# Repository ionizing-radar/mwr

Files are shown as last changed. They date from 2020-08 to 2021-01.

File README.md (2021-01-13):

# mwr
## Mobile Wheeled Robot library

I'm making a robot, and I want the code to be in more than one place.

## Joystick Controls for Two Wheels

Motor control takes the vector (r, θ) as an input from the joystick, where r spans (0,1) and θ spans (-π, π).

These polar coordinates are translated from (x,y) coordinates of the joystick control, where θ = arctan(Y-offset/X-offset).
###### Note: thats written in Java, so it's Math.arctan**2**(y,x) and not straight up arctan because of course it isn't. X and Y offset have also been translated -π/2, aka 90 degrees counter-clockwise by (x,y) -> (-y,x) so it's actually arctan(x,-y). Confusing at first, but since arctan takes a fraction it saves having to translate the polar coordinate by giving arctan translated cartesian coordinates.

R, or radius, is the strength of the joystick direction. So 1 is full power and 0 is of course full stop, with any value in between.

These polar coordinates assume UP on the joystick is 0 degrees for forwards, and DOWN is π and -π degrees for backwards. (Negative and postive π are equal in terms of the direction of the joystick, since in radians 0 is congruent to 2π). LEFT and RIGHT are hard turns to the LEFT and RIGHT, while 45 degrees LEFT and RIGTH are slow turns. The difference between hard and slow turn is that the motor on the side to turn towards is either reversing or stopped. So for a hard turn LEFT the left motor is full reverse and the right motor is full forwards, and the opposite for a hard turn RIGHT.

For any left turn between 45 degrees and directly forwards, the left motor will slowly increase to full from stop, and between 45 and 90 degrees left the motor will slowly increase reverse speed to full reverse. For forwards movement on the joystick this can be modeled as cos(2θ) and for backwards on the joystick it is sin(2θ-π/2).

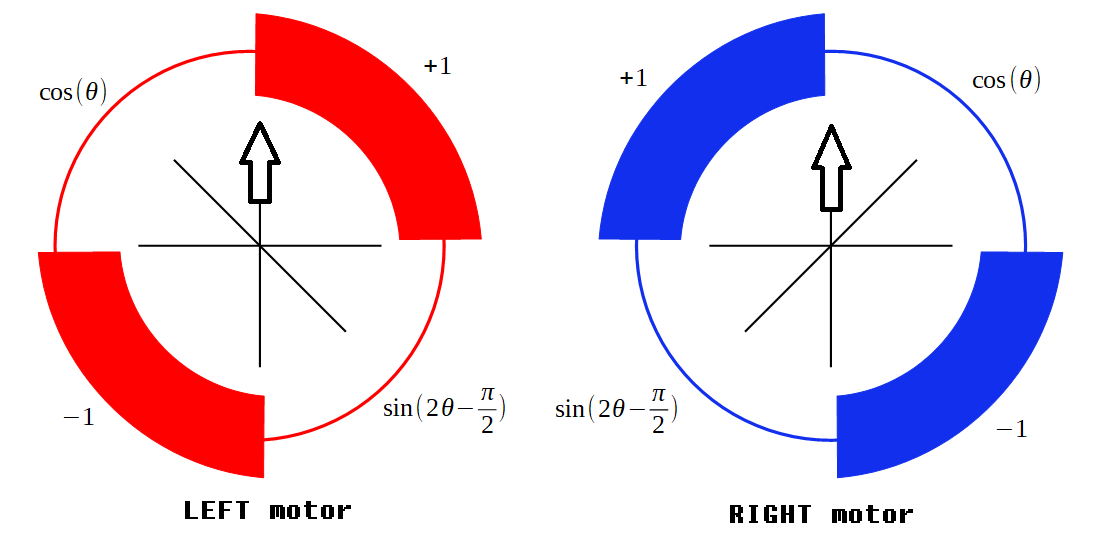
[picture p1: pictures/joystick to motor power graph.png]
Joystick-Motor power graph


###### For more reading on polar coordinates check out https://www.mathsisfun.com/polar-cartesian-coordinates.html and https://mathworld.wolfram.com/PolarCoordinates.html

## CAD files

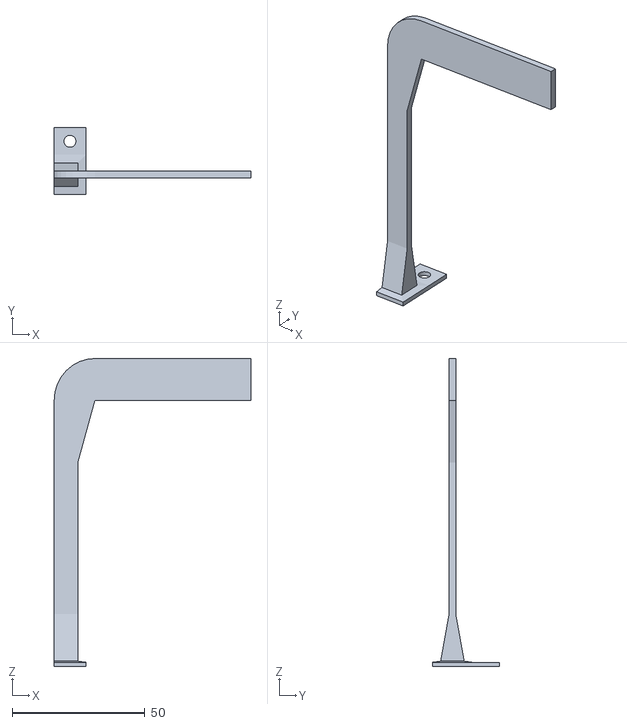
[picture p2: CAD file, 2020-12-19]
shapes/camera_gimbal/camera mount.stl
74.1 x 25.2 x 115.9

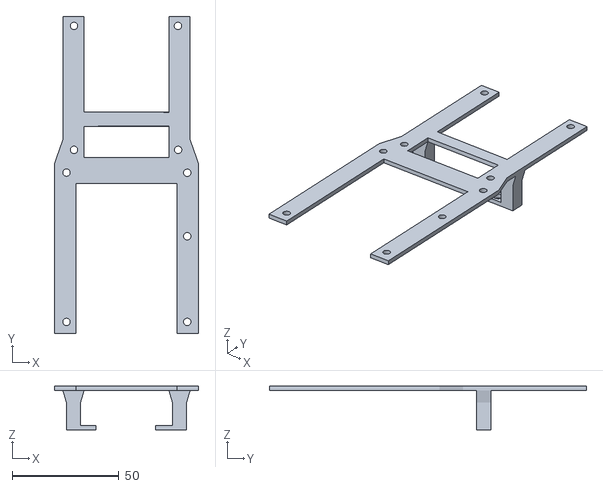
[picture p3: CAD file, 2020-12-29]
shapes/wishbone.stl
67.6 x 149.0 x 20.6

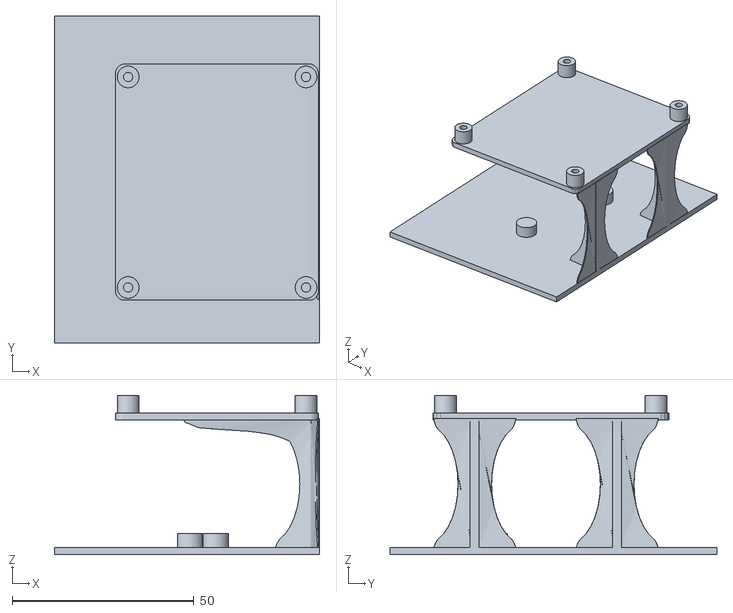
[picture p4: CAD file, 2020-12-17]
shapes/MWR - rpi and L293D breakout mount.stl
73.0 x 90.0 x 43.9

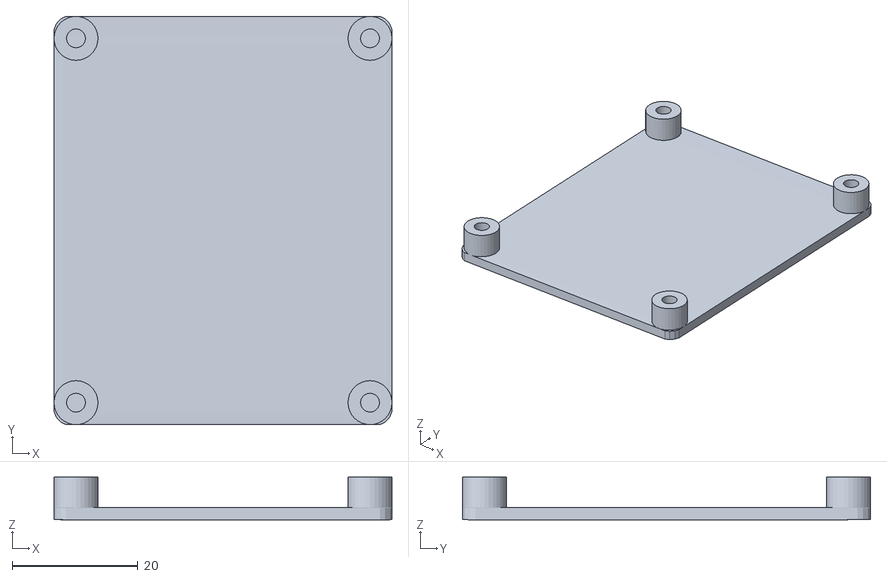
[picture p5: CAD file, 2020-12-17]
shapes/pi mounting base.stl
53.8 x 65.0 x 6.81

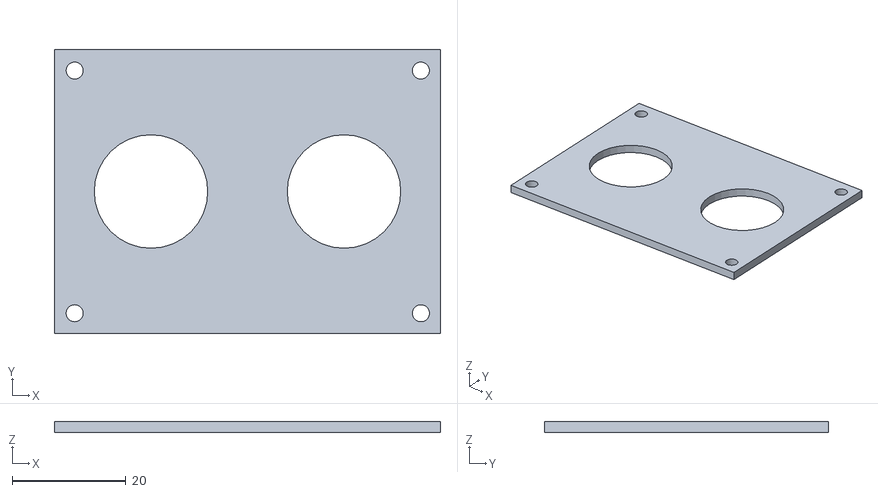
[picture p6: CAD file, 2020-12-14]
shapes/switch plate.stl
68.0 x 50.0 x 2.00

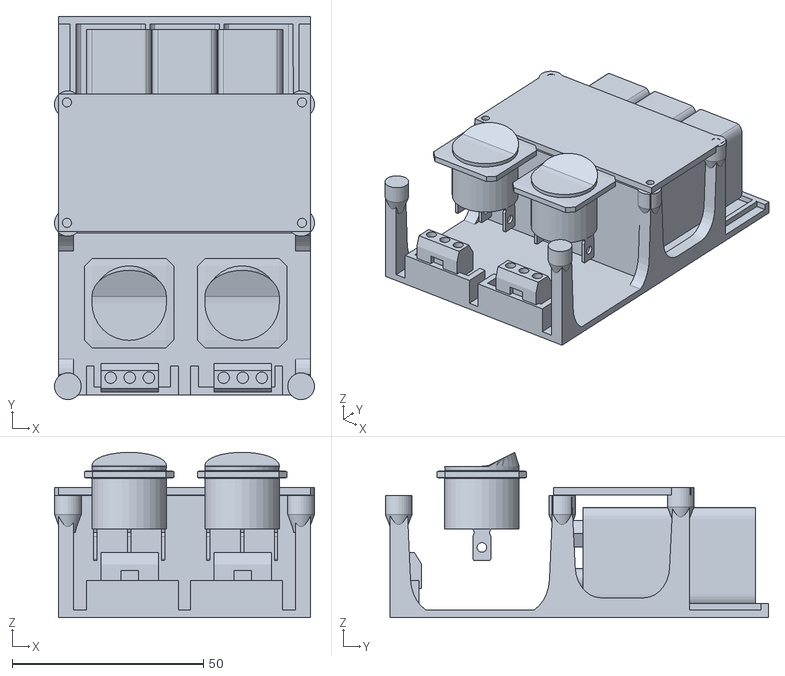
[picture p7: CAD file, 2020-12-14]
shapes/DC-DC board with battery holder and switch mounts.stl
68.0 x 100.3 x 43.2

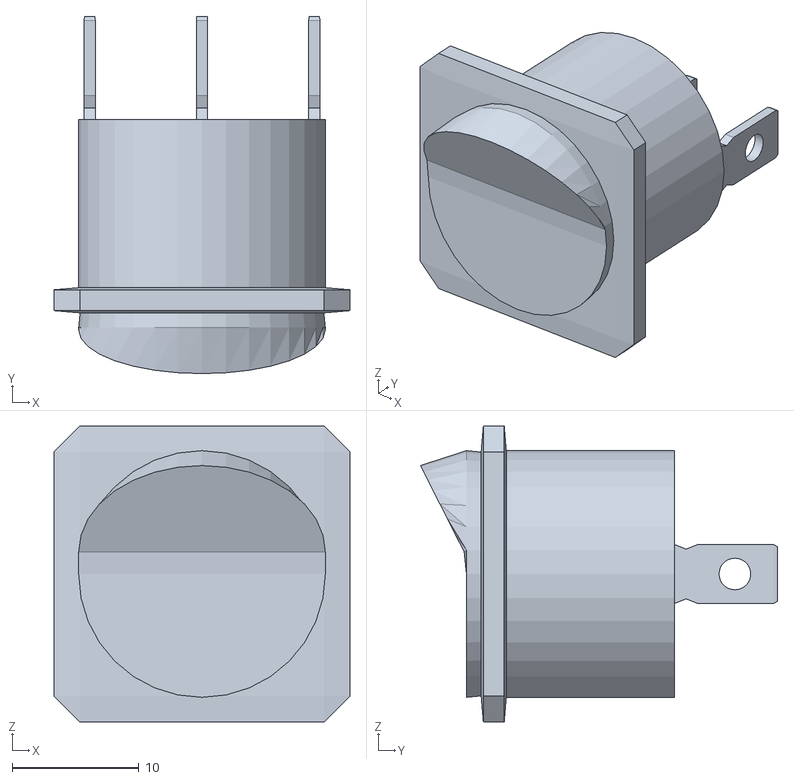
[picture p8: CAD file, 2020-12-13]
shapes/rocker switch - 22mm.stl
23.4 x 28.2 x 23.4

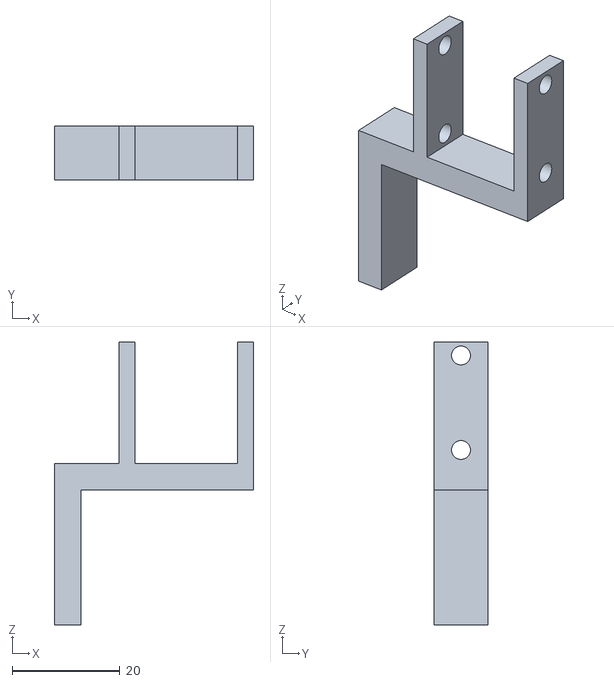
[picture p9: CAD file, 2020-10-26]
shapes/gebildet motor housing cradle mount.stl
37.0 x 10.0 x 52.5

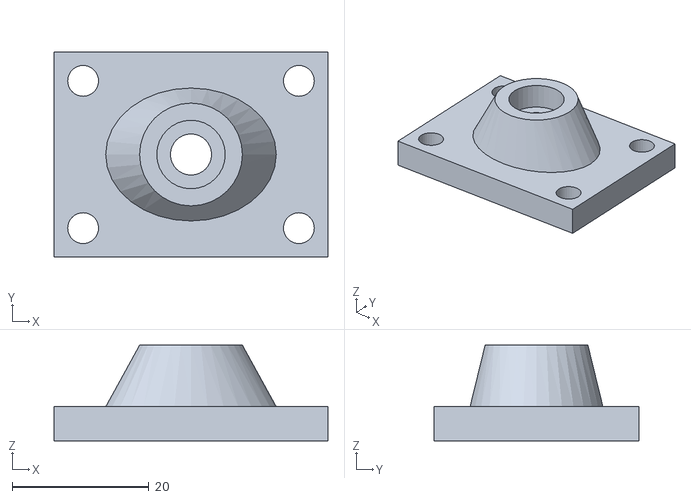
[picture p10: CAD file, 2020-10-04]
shapes/drum collar.stl
40.0 x 30.0 x 14.0

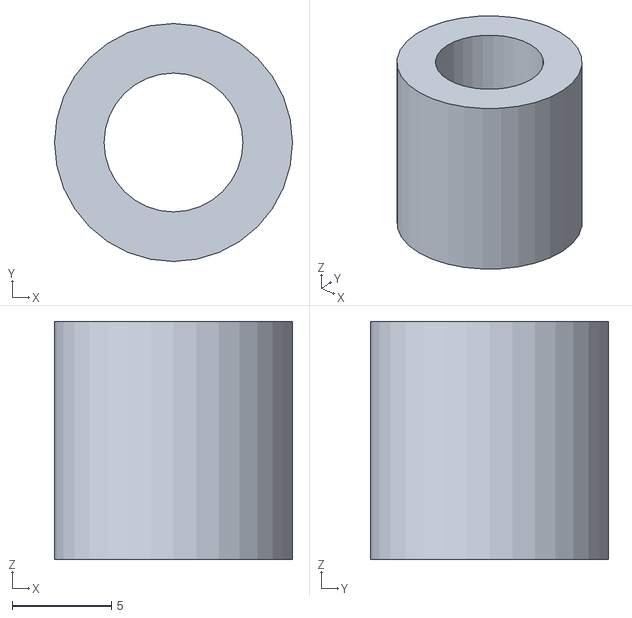
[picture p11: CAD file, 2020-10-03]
shapes/12mm collar.stl
12.0 x 12.0 x 12.0

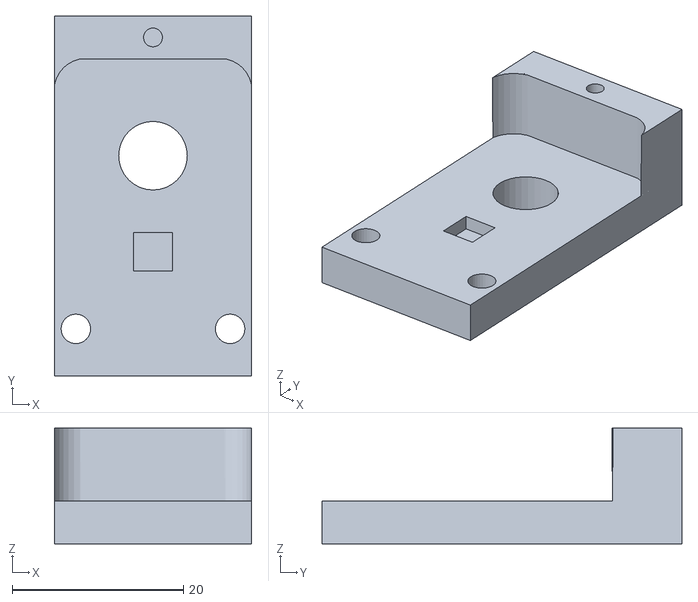
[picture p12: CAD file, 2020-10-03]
shapes/gebildet motor housing mount.stl
23.0 x 42.0 x 13.5

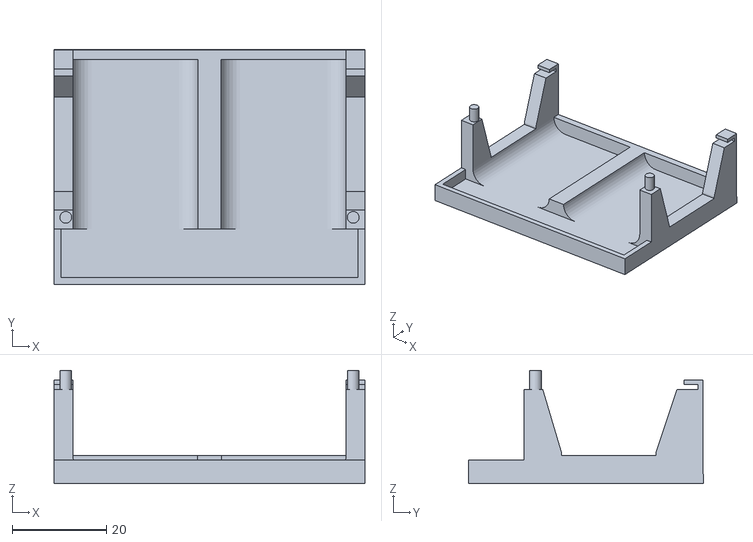
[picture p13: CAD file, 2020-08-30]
shapes/DC-DC board with battery holder.stl
66.0 x 49.9 x 24.0

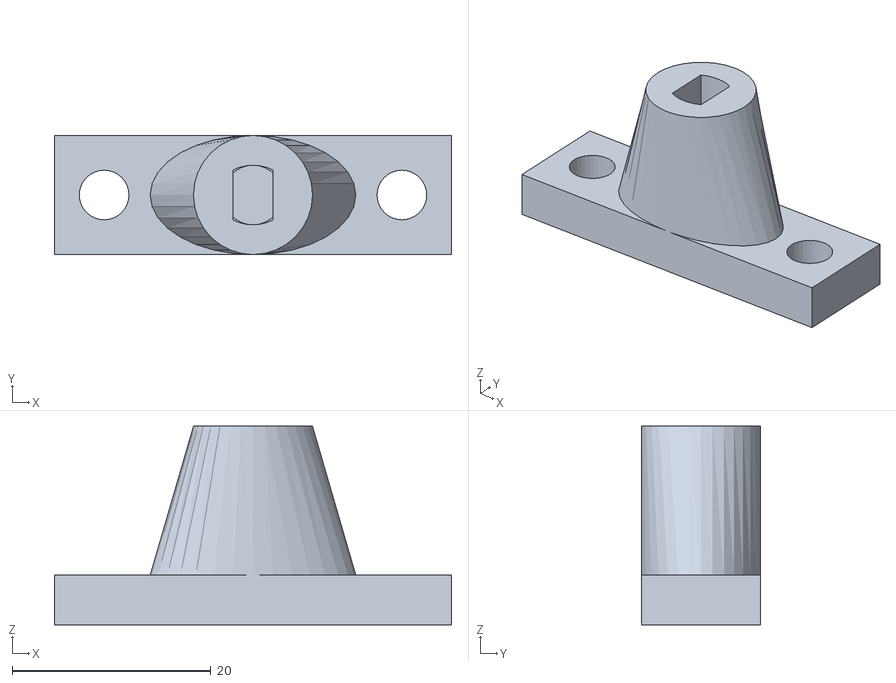
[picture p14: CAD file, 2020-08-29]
shapes/keyed Gebildet drum mount.stl
40.0 x 12.0 x 20.0

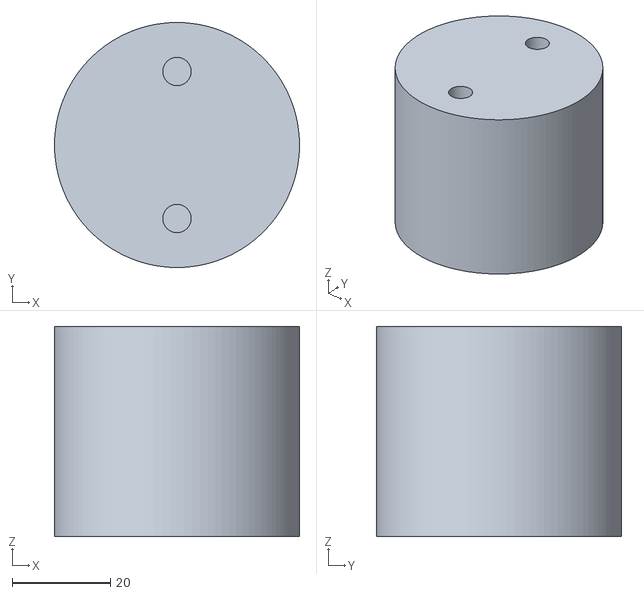
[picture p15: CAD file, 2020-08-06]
shapes/43mm drum.stl
50.0 x 50.0 x 42.9

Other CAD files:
shapes/10mm hole - LH drive wheel arm v2.stl
shapes/ULN2003 mount.stl
shapes/camera mount.blend

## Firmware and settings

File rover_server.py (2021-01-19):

#!/usr/bin/python3

import threading
import concurrent.futures
import socket
import queue
import json
import math

import RPi.GPIO as GPIO
import time

from MotorController import MotorController

# network connection server defaults
DEFAULT_HOST = '192.168.0.205'
DEFAULT_PORT = 23500

# server socket, listens for incoming connections and then handles JSON on that socket
## the input stream should only contain JSON, otherwise it'll bork and weird things happen
def serverSocket(serverIP, serverPort, q):
	while True:
		# simple echo server
		try:
			with socket.socket(socket.AF_INET, socket.SOCK_STREAM) as s:
				print ('Listening on',serverIP,':',serverPort)
				s.bind((serverIP, serverPort))
				s.listen(2)
				conn, addr = s.accept()
				# make a connection
				with conn:
					print('Connect by ', addr)
					while True:
						# get data, echo it, loop
						data = conn.recv(1024)
						if not data:
							break
						else:
							q.put(data) # enqueue data
						conn.sendall(data) # echo
		except KeyboardInterrupt:
			conn.close()

def commandQueue(q):

	print("initiallzing MotorController")
	Motor1A = 31
	Motor1B = 29
	Motor1E = 33
	Motor2A = 13
	Motor2B = 11
	Motor2E = 15
	drive = MotorController(Motor1A, Motor1B, Motor1E, Motor2A, Motor2B, Motor2E)
	drive.stop()

	print("staring Q parser")
	while True:
		item = q.get().decode("utf-8")
		try:
			command = json.loads(item)
			if ("drive" in command.keys()):
				driveCommand = command.get("drive")
				print(driveCommand)
				r = driveCommand.get("r")
				theta = driveCommand.get("theta")
				while (theta > math.pi):
					theta -= (2*math.pi)
				while (theta < (-math.pi)):
					theta += (2*math.pi)
				if (r > 0):					
					if (theta > (math.pi/2)): # back left
						drive.setMotor(r, math.sin(2*theta-math.pi/2), -1)
					elif (theta > 0): # forward left
						drive.setMotor(r, 1, math.cos(2*theta))
					elif (theta > (-1 * math.pi/2)): # forward right
						drive.setMotor(r, math.cos(2*theta), 1)
					else: # back right
						drive.setMotor(r, -1, math.sin(2*theta-math.pi/2))
				else:
					drive.setMotor(0,0,0)
			else:
				print("command.keys(): "+command.keys())
		except TypeError:
			print("TypeError with json input:")
			print(item)
		except ValueError:
			print("ValueError with json input:")
			print(item)

		# //TOOD: set motors to zero if motors non-zero and no input for 100ms

def main():
	
	q = queue.Queue()

	threads = list();
	threads.append(threading.Thread(target=serverSocket, args=(DEFAULT_HOST, DEFAULT_PORT, q,)))
	threads.append(threading.Thread(target=commandQueue, args=(q,)))


	
	for thread in threads:
		thread.start()

if __name__ == "__main__":
	print("starting...")
	main()

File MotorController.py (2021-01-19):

import RPi.GPIO as GPIO
import time

class MotorController:

    MOTOR_PWM_FREQ = 100

    Motor1A = None
    Motor1B = None
    Motor1E = None
    Motor2A = None
    Motor2B = None
    Motor2E = None
    Motors = None


    motor1_forward = None
    motor1_reverse = None
    motor2_forward = None
    motor2_reverse = None
    def __init__(self, Motor1A, Motor1B, Motor1E, Motor2A, Motor2B, Motor2E):
        # RUSSEL 1.0 used this pinout:
        #   Motor1A=31, Motor1B=29, Motor1E=33, Motor2A=13 ,Motor2B=11, Motor2E=15
        # GPIO pin definitions
        GPIO.setmode(GPIO.BOARD)
        self.Motor1A = Motor1A
        self.Motor1B = Motor1B
        self.Motor1E = Motor1E
        self.Motor2A = Motor2A
        self.Motor2B = Motor2B
        self.Motor2E = Motor2E        
        self.MOTORS = [Motor1A, Motor1B, Motor1E, Motor2A, Motor2B, Motor2E]
        for motor in self.MOTORS:
            GPIO.setup(motor,GPIO.OUT)       

        self.motor1_forward = GPIO.PWM(self.Motor1A, MotorController.MOTOR_PWM_FREQ) 
        self.motor1_reverse = GPIO.PWM(self.Motor1B, MotorController.MOTOR_PWM_FREQ)

        self.motor2_forward = GPIO.PWM(self.Motor2A, MotorController.MOTOR_PWM_FREQ) 
        self.motor2_reverse = GPIO.PWM(self.Motor2B, MotorController.MOTOR_PWM_FREQ)

    def __del__(self):
        # stop all the motors
        self.motor1_forward.stop()
        self.motor1_reverse.stop()
        self.motor2_reverse.stop()
        self.motor2_forward.stop()
        # set the GPIO free, to roam in the wild surviving on stray voltage and kind strangers
        GPIO.cleanup()

    def dothings(self):
        print("doing a thing!")

    # helper function to stop motors, directly calls setMotor with 0's as inputs
    def stop(self):
        self.setMotor()

    # set speed of motor, assumes using L293 driver
    #  - motorX_forward and motorX_reverse shouldn't be both be on as the +/- motor terminals
    def setMotor(self, power=0, motor1=0, motor2=0):
        print("setMotor ({0},{1},{2})".format(power, motor1, motor2))
        if (power > 1): power == 1
        power *= 100
        if (power == 0):
            GPIO.output(self.Motor1E,GPIO.LOW)
            self.motor1_forward.stop()
            self.motor1_reverse.stop()
            GPIO.output(self.Motor2E,GPIO.LOW)
            self.motor2_forward.stop()
            self.motor2_reverse.stop()
            return
        if (motor1 == 0):            
            GPIO.output(self.Motor1E,GPIO.LOW)
            self.motor1_forward.stop()
            self.motor1_reverse.stop()
        elif (motor1 > 0):            
            GPIO.output(self.Motor1E,GPIO.HIGH)
            self.motor1_forward.start(power*motor1)
            self.motor1_reverse.stop()
        elif (motor1 < 1):            
            GPIO.output(self.Motor1E,GPIO.HIGH)
            self.motor1_reverse.start(abs(power*motor1))
            self.motor1_forward.stop()
        if (motor2 == 0):
            GPIO.output(self.Motor2E,GPIO.LOW)
            self.motor2_forward.stop()
            self.motor2_reverse.stop()
        elif (motor2 > 0):
            GPIO.output(self.Motor2E,GPIO.HIGH)
            self.motor2_forward.start(power*motor2)
            self.motor2_reverse.stop()
        elif (motor2 < 1):
            GPIO.output(self.Motor2E,GPIO.HIGH)
            self.motor2_reverse.start(abs(power*motor2))
            self.motor2_forward.stop()


# # enable M1, init motor at OFF
# GPIO.output(Motor1E, GPIO.HIGH)
# GPIO.output(Motor1B, GPIO.LOW)

# try:    
#     while True:
#             for dutyCycle in range(0,101,20):
#                 motor1_forward.ChangeDutyCycle(dutyCycle)
#                 print(dutyCycle)
#                 time.sleep(0.5)
#             for dutyCycle in range(95,0,-5):
#                 motor1_forward.ChangeDutyCycle(dutyCycle)
#                 print(dutyCycle)
#                 time.sleep(0.1)
# except KeyboardInterrupt:
#         print("Ctrl C")

# motor1_forward.stop()
# GPIO.cleanup

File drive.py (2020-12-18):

import RPi.GPIO as GPIO
from time import sleep
from Robot import Wheel


# init Robot
Wheel.DEBUG = True

# init GPIO
print GPIO.RPI_INFO
GPIO.setmode(GPIO.BOARD)

# init left wheel
#	GPIO 13 (pin 33) as enable
#	GPIO 6 (pin 31) as forward
#	GPIO 5 (pin 29) as reverse

left = Wheel(33, 31, 29)

# init right wheel 
#	GPIO 22 (pin 15) as enable
#	GPIO 27 (pin 13) as forward
#	GPIO 17 (pin 11) as reverse
right = Wheel(15, 13, 11)

#right.forward()
#left.stop()



left.start()
right.start()
sleep(2)
left.stop()
right.stop()
left.reverse()
right.reverse()
sleep(2)
left.stop()
right.stop()



GPIO.cleanup()

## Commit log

2018-01-01 added basic motor testing
2018-01-01 motor class definition
2018-01-02 added Wheel class to Robots
2020-08-05 Add files via upload
    ULN2003 control board mounting plate
    [ULN2003 mount.stl]
2020-08-06 10mm hole in angled arm
    10mm hole on arm, made to fit a 10mm bearing
    [10mm hole - LH drive wheel arm v2.stl]
2020-08-06 43mm drum
    43mm wide, 25mm radius
    5mm hole on centre one end, two 5mm hole on center line each 15mm from center.
    [43mm drum.stl]
2020-08-29 Add files via upload
    fits to 43mm drum, keyed for Gebildet 3-6DC motor shaft
    [keyed Gebildet drum mount.stl]
2020-08-29 adapter for mount shaft to 43 drum
    fits Gibildet DC motor shaft, corrected shaft and mounting hole sizes
    [keyed Gebildet drum mount.stl]
2020-08-29 adapter to mount shaft to 43 drum
    fits Gebildet DC motor shaft, without the extra hole at the bottom
    [keyed Gebildet drum mount.stl]
2020-08-29 buck converter and battery mount
    Made to fit LM2596S DC-DC Buck Converter on a 66 x 36 mm board, with two 9V batteries held with in place with wrap-around velcro. Fits this: https://www.amazon.co.uk/Adjustable-Converter-Regulator-St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
    [DC-DC board with battery holder.stl]
2020-08-30 buck converter and battery mount
    fits LM2596S buck converter, with space for two 9V batteries
    [DC-DC board with battery holder.stl]
2020-08-31 DC buck converter frame
    with space for two 9V batteries, improved so that the frame has a positive hold on the circuit board.
2020-10-03 12mm collar with 6 mm inside diameter
    measure once ==> print twice
    [12mm collar.stl]
2020-10-04 collar to mount drum to frame
    I probably didn't need this, but I don't have short M5 screws to mount the bearing to the drum so I need a thingy
    [drum collar.stl]
2020-10-26 cradle mount from the side
    Take Two at a Gebildet motor mount. The first one was ok, but offset the motor mount point too far to one side. This one will offset the centre of balance, but if KSP has me anything, I'm sure it can be fixed with braces.
    Oh and the top hole is a bit off, needs to move up about 2mm
    [gebildet motor housing cradle mount.stl]
2020-10-26 Gebildet cradle mount
    Take Two (point 1) at a Gebildet motor mount. The first one was ok, but offset the motor mount point too far to one side. This one will offset the centre of balance, but if KSP has me anything, I'm sure it can be fixed with braces.
    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
    [gebildet motor housing cradle mount.stl]
2020-10-27 DC-DC board mount
    - carries two 9V batteries
    - mounting plate for two round rocker switches (28mm plate with 20.5mm mounting hole)
    [DC-DC board with battery holder and switch mounts.stl]
2020-12-13 rocker switch
    There's also a 27 mm collar secures the switch to the mounting surface.
    [rocker switch - 22mm.stl]
2020-12-14 Add files via upload
    - carries three 9V batteries
    - mounts 2x4pin terminal connectors
    - fits, but needs additional, mounting plate for two round rocker switches
    [DC-DC board with battery holder and switch mounts.stl]
2020-12-14 switch plate
    rocker switch plate, goes with https://github.com/ionizing-radar/mwr/blob/master/DC-DC%20board%20with%20battery%20holder%20and%20switch%20mounts.stl
    [switch plate.stl]
2020-12-17 template for mounting plate for RPi 3B
    [pi mounting base.stl]
2020-12-17 franken-mount
    franken-mount for an RPi 3B and a bespoke breakout board mounting L293D
    [MWR - rpi and L293D breakout mount.stl]
2020-12-18 still mucking about motors that won't stop
    [motor_test.py]
2020-12-18 mount for RPi camera
    made to fit RUSSELL 1.0
    lifts 9cm up and 5cm to the side
    [camera mount.stl]
2020-12-18 mount for RPi camera
    made to fit RUSSELL, holds camera 9cm up and 5 cm over from the mount point
    [camera mount.blend]
2020-12-18 mount for RPi camera
    fits RUSSELL, holds camera 9cm up and 5 cm over from the mount point
    [camera mount.stl]
2020-12-22 folder stucture
    [10mm hole - LH drive wheel arm v2.stl, 12mm collar.stl, 43mm drum.stl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]
2020-12-22 directory structure
    [10mm hole - LH drive wheel arm v2.stl, 12mm collar.stl, 43mm drum.stl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]
2020-12-22 gimbal directory
    [camera mount.stl]
2020-12-29 mounts spine and RPi to Z-gimbal
    [wishbone.stl]
2020-12-30 testing socket connections
2021-01-01 echo server
    [camera mount.blend]
2021-01-11 threaded rover server
2021-01-11 threaded network socket and network data processing
2021-01-13 power graph for motors
    Joystick to motor power with UP meaning forwards at 0 degrees.
    RED for LEFT motor
    BLUE for RIGHT motor
2021-01-13 Update README.md
    math is fun, plus there's a graph that I translated (no pun intended) from a white board
2021-01-13 pwm test
2021-01-13 pwm working tes
2021-01-14 pwm in rover_server
2021-01-15 pwm server
2021-01-18 bi-directional pwm
2021-01-18 pwm testing
2021-01-19 working PWM from network json
2021-03-06 spi test
2021-04-03 spi testing
